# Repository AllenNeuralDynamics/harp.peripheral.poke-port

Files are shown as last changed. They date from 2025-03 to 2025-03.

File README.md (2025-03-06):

# harp.peripheral.delphi-poke

companion circuit board for Mouse "Poke" Port.

<p align="center">
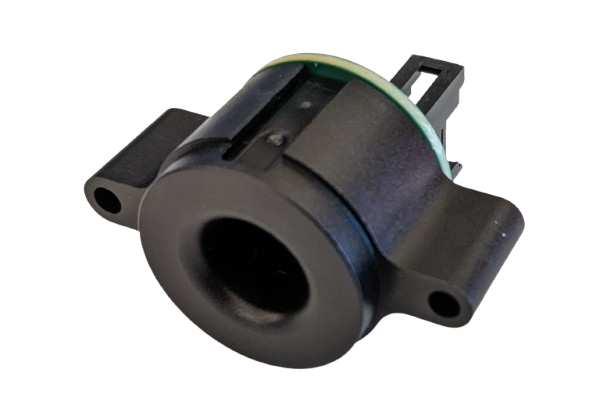
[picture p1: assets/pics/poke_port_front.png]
  
&nbsp; &nbsp; &nbsp; &nbsp;
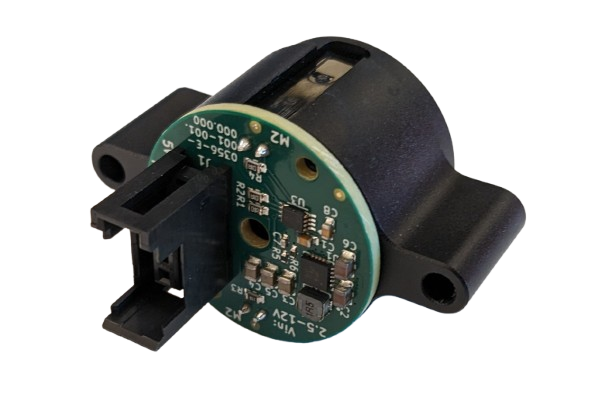
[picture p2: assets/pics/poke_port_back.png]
  
</p>

> [!NOTE]
> This repository is for the electronics hardware only. For the physical Poke Port, see the [CAD Model](https://cad.onshape.com/documents/066d94ed47eba590ef197816/w/7206c419a0e3b3641e025c3e/e/6c7b2bb3fef528a1d7258398) (Onshape).

## Assembly

## Installation

For installing the Poke Port into a mouse home cage, we recommend drilling out a 25mm hole with a hole saw ([example](https://www.mcmaster.com/products/hole-saws/diameter~25-mm/)), and installing M3 heat-set inserts into the home cage for threaded mounting.

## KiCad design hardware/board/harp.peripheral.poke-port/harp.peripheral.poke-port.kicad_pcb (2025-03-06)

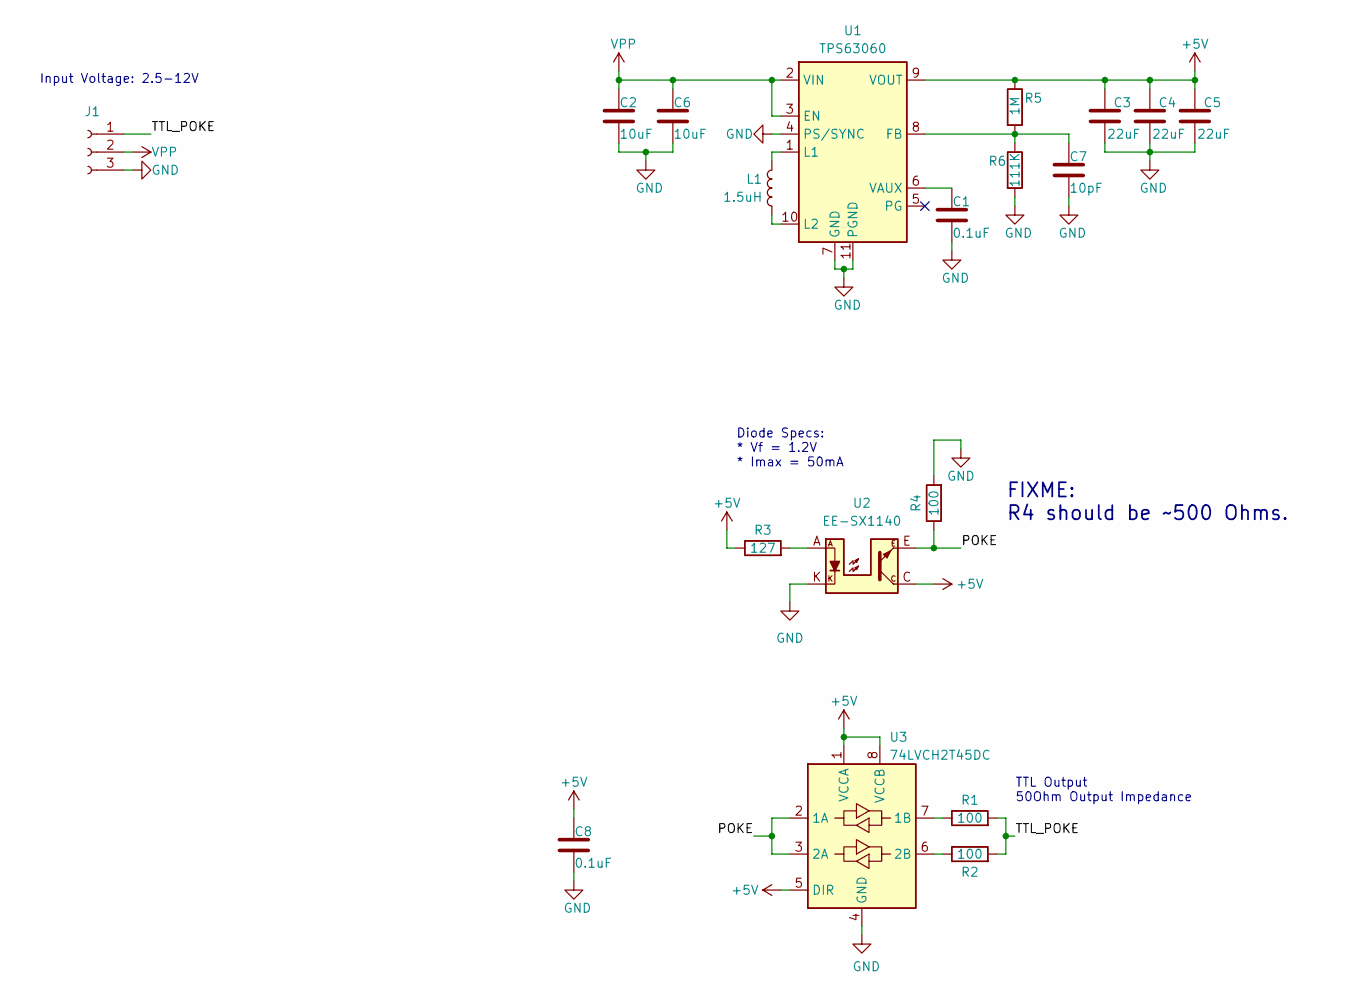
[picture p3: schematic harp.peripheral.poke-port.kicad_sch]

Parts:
C1, C8: 0.1uF; C_0603_1608Metric
C2, C6: 10uF; C_0805_2012Metric
C3, C4, C5: 22uF; C_0805_2012Metric; Rated Voltage 10V
C7: 10pF; C_0402_1005Metric
J1: Conn_01x03_Socket; 3M_Mini-Clamp-Socket-37203-62B3-003PL-1x3_Vertical
L1: 1.5uH; L_Murata_1226AS-H-1R5N=P2
R1, R2, R4: 100; R_0603_1608Metric; Tolerance 1%
R3: 127; R_0603_1608Metric
R5: 1M; R_0402_1005Metric
R6: 111K; R_0402_1005Metric
U1: TPS63060; Texas_S-PWSON-N10_ThermalVias
U2: EE-SX1140
U3: 74LVCH2T45DC; VSSOP-8_2.3x2mm_P0.5mm

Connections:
+5V: C3.2, C4.2, C5.2, C8.1, R3.1, R5.1, U1.9 (VOUT), U2.C, U3.1 (VCCA), U3.5 (DIR), U3.8 (VCCB)
/POKE: R4.1, U2.E, U3.2 (1A), U3.3 (2A)
/TTL_POKE: J1.1, R1.2, R2.2
GND: C1.2, C2.2, C3.1, C4.1, C5.1, C6.2, C7.2, C8.2, J1.3, R4.2, R6.2, U1.4 (PS/SYNC), U1.7 (GND), U1.11 (PGND), U2.K, U3.4 (GND)
unnamed: R3.2, U2.A
unnamed: C7.1, R5.2, R6.1, U1.8 (FB)
unnamed: L1.1, U1.1 (L1)
unnamed: L1.2, U1.10 (L2)
unnamed: C1.1, U1.6 (VAUX)
unnamed: R1.1, U3.7 (1B)
unnamed: R2.1, U3.6 (2B)
VPP: C2.1, C6.1, J1.2, U1.2 (VIN), U1.3 (EN)

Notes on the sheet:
TTL Output 50Ohm Output Impedance
Input Voltage: 2.5-12V
FIXME: R4 should be ~500 Ohms.
Diode Specs: * Vf = 1.2V * Imax = 50mA

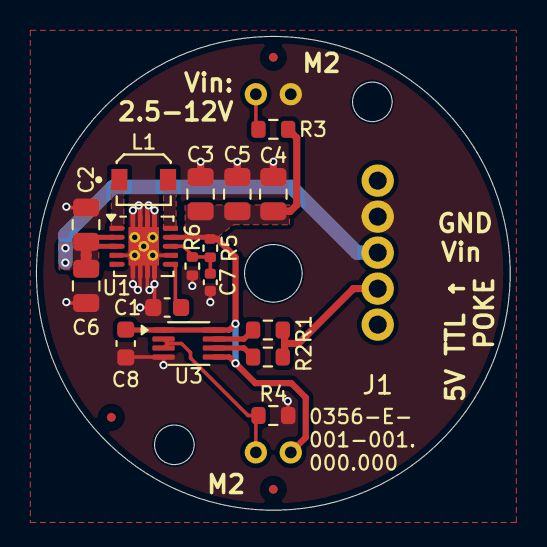
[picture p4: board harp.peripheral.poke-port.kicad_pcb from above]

Board: 2 copper layers, 26.3 x 26.3 mm, 19 parts (1 on the bottom side), 12 nets.

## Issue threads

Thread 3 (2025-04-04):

Poke port with adjusted depth for Pirouette cage

Prattbuw, 2025-04-04:
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

The poke port depth needs to be adjusted to the wall thickness (5.5 mm) of the Pirouette cage, so that the face of the port is flush with the inner wall of the cage. Also, we need to make sure the current port depth (3.5mm) is correct for the regular home cages in the vivarium, which appear to be close to 3mm in wall thickness. Overall, the goal here is to have the face of the port be flush with the inner wall of whatever cage we are using. Given this, we will likely need poke ports with different port depths.

Poofjunior, 2025-04-04:
@Prattbuw let me know if this is what you're looking for:

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

Distance is now 5.5mm from the front surface.

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

Prattbuw, 2025-04-14:
@Poofjunior, this is exactly what I am looking for. I confirmed that the port depth should be 5.5mm for the pirouette boxes. If you could order the updated poke port, that would be great!

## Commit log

2025-02-03 fix merge conflicts
    [harp.peripheral.poke-port.kicad_pcb, harp.peripheral.poke-port.kicad_sch]
2025-02-03 add 3d models
    [harp.peripheral.poke-port.kicad_pcb, harp.peripheral.poke-port.kicad_sch]
2025-02-03 update silkscreen
    [harp.peripheral.poke-port.kicad_pcb]
2025-02-10 update min soldermask bridge to 0.2mm
    [harp.peripheral.poke-port.kicad_pcb, harp.peripheral.poke-port.kicad_sch]
2025-03-06 add schematic errata note
    [harp.peripheral.poke-port.kicad_sch]
2025-03-06 update photointerruptor silkscreen
    [harp.peripheral.poke-port.kicad_pcb]
2025-03-06 update photointerrupter resistor
    [harp.peripheral.poke-port.kicad_sch]
